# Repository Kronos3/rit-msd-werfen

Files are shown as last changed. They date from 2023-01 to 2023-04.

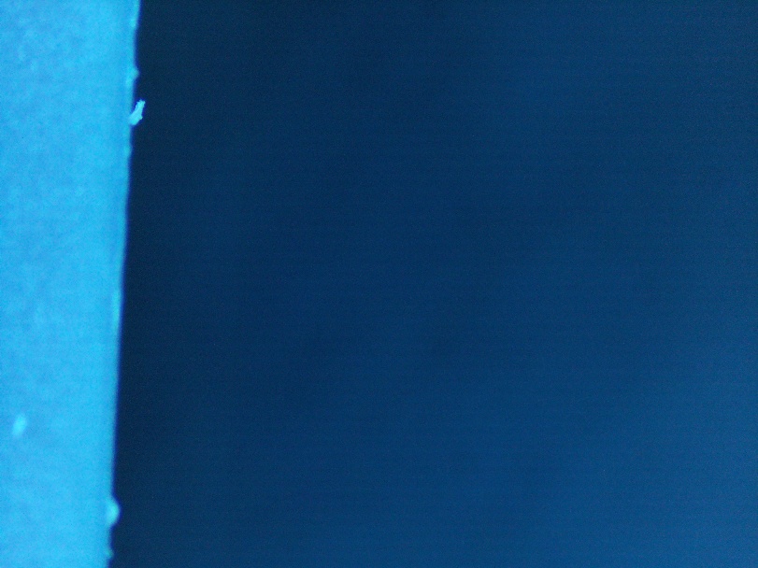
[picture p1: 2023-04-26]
prototyping/test-edge.jpg

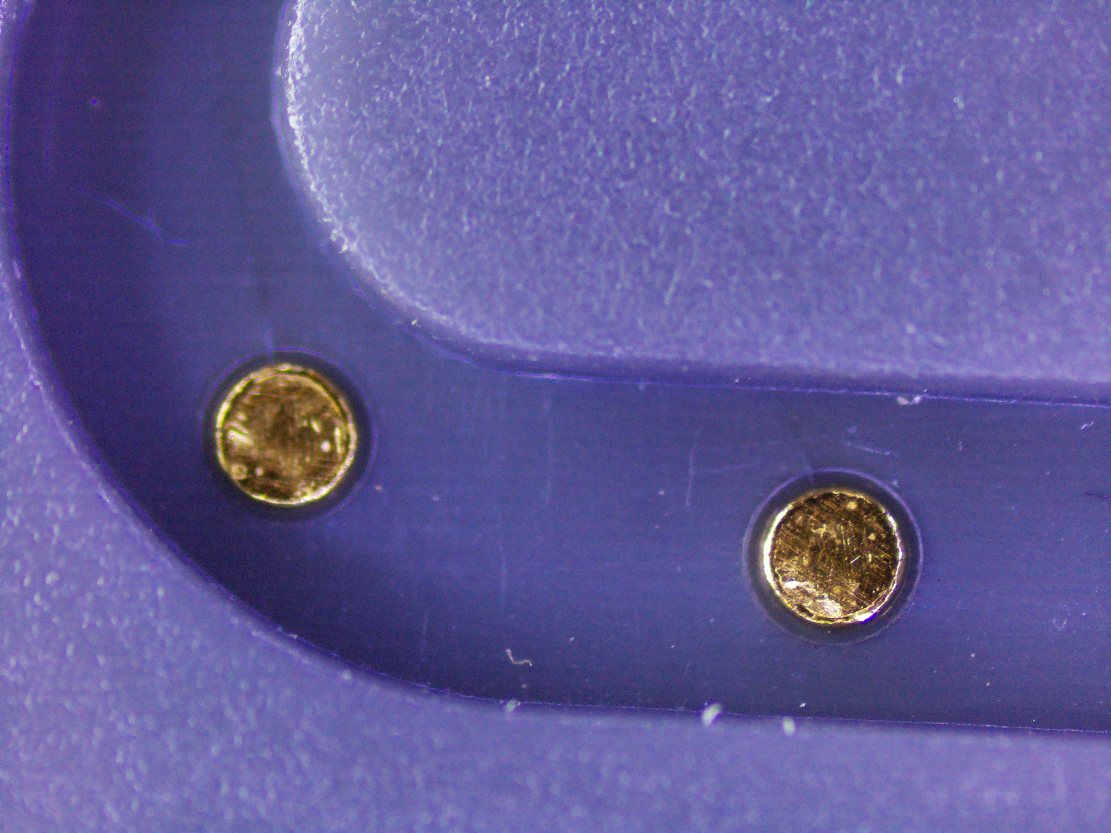
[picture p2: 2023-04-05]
prototyping/testgold2.jpg

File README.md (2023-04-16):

# RIT-Werfen Inspection

## Overview

Layout for this project:
  - /pcb - KiCAD Design file for the PCB
  - /mc - Microcontroller firmware for STM32L476RG
  - /prototyping - Test images and Jupyter Notebooks used to prototype code
  - /src - Code running on the Raspberry Pi and in the browser
    - frontend/ - ReactJS (Typescript) program for frontend browser code
    - rit/ - Middleware that abstract the behavior of cameras and MC packet interface
    - web/ - FastAPI that exposes webendpoints for the frontend to submit requests to
    - camera_focusing.py - Script that boots up a QT Program to view the camera live

## Building

The microcontroller code can be built using CMake + GCC Arm toolchain.
You should use a relatively recent GCC Arm toolchain (`arm-none-eabi-gcc`)

### Dependency installation (Ubuntu)

On Ubuntu, run the following to install the dependencies:

```
sudo apt install gcc-arm-none-eabi cmake make
```

### Building PCB code

```
mkdir -p mc/build
cd mc/build
cmake -DCMAKE_C_COMPILER=arm-none-eabi-gcc -DCMAKE_CXX_COMPILER=arm-none-eabi-g++ ../
```

Now that the code is built, you can flash the PCB using an ST-Link or the ST-Link found on a STM32 Nucleo board using SWD via OpenOCD. I'd recommend using a Nucleo board for flashing along with an IDE like CLion that can set up, build and flash firmware for you.

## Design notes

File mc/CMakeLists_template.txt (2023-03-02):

#THIS FILE IS AUTO GENERATED FROM THE TEMPLATE! DO NOT CHANGE!
set(CMAKE_SYSTEM_NAME Generic)
set(CMAKE_SYSTEM_VERSION 1)
cmake_minimum_required(VERSION 3.20)

# specify cross compilers and tools
set(CMAKE_TRY_COMPILE_TARGET_TYPE STATIC_LIBRARY)

# project settings
project(Werfen C CXX ASM)
set(CMAKE_CXX_STANDARD 14)
set(CMAKE_C_STANDARD 99)

#Uncomment for hardware floating point
add_compile_definitions(ARM_MATH_CM4;ARM_MATH_MATRIX_CHECK;ARM_MATH_ROUNDING)
add_compile_options(-mfloat-abi=hard -mfpu=fpv4-sp-d16)
add_link_options(-mfloat-abi=hard -mfpu=fpv4-sp-d16)

#Uncomment for software floating point
#add_compile_options(-mfloat-abi=soft)

add_compile_options(-mcpu=cortex-m4 -mthumb -mthumb-interwork)
add_compile_options(-ffunction-sections -fdata-sections -fno-common -fmessage-length=0)

# uncomment to mitigate c++17 absolute addresses warnings
#set(CMAKE_CXX_FLAGS "${CMAKE_CXX_FLAGS} -Wno-register")

if ("${CMAKE_BUILD_TYPE}" STREQUAL "Release")
    message(STATUS "Maximum optimization for speed")
    add_compile_options(-Ofast)
elseif ("${CMAKE_BUILD_TYPE}" STREQUAL "RelWithDebInfo")
    message(STATUS "Maximum optimization for speed, debug info included")
    add_compile_options(-Ofast -g)
elseif ("${CMAKE_BUILD_TYPE}" STREQUAL "MinSizeRel")
    message(STATUS "Maximum optimization for size")
    add_compile_options(-Os)
else ()
    message(STATUS "Minimal optimization, debug info included")
    add_compile_options(-Og -g)
endif ()

include_directories(
        Core/Inc
        Drivers/STM32L4xx_HAL_Driver/Inc
        Drivers/STM32L4xx_HAL_Driver/Inc/Legacy
        Drivers/CMSIS/Device/ST/STM32L4xx/Include
        Drivers/CMSIS/Include
        Core/Inc
        Drivers/STM32L4xx_HAL_Driver/Inc
        Drivers/STM32L4xx_HAL_Driver/Inc/Legacy
        Drivers/CMSIS/Device/ST/STM32L4xx/Include
        Drivers/CMSIS/Include
)

add_definitions(
        -DDEBUG
        -DUSE_HAL_DRIVER
        -DSTM32L476xx
        -DDEBUG
        -DUSE_HAL_DRIVER
        -DSTM32L476xx)

file(GLOB_RECURSE SOURCES
        "Core/*.*"
        "Drivers/STM32L4xx_HAL_Driver/*.*"
        )

set(LINKER_SCRIPT ${CMAKE_SOURCE_DIR}/STM32L476RGTX_FLASH.ld)

add_link_options(-Wl,-gc-sections,--print-memory-usage,-Map=${PROJECT_BINARY_DIR}/${PROJECT_NAME}.map)
add_link_options(-mcpu=cortex-m4 -mthumb -mthumb-interwork)
add_link_options(-T ${LINKER_SCRIPT})

include_directories(src)
add_executable(${PROJECT_NAME}.elf
        ${SOURCES}
        ${LINKER_SCRIPT}
        src/gbl.h
        src/log.c
        src/log.h
        src/crc.c
        src/crc.h
        src/motor.c
        src/motor.h
        src/packet.c
        src/packet.h
        src/switch.c
        src/switch.h
        src/led.c
        src/led.h
        src/circular_buffer.c
        src/circular_buffer.h
)

set(HEX_FILE ${PROJECT_BINARY_DIR}/${PROJECT_NAME}.hex)
set(BIN_FILE ${PROJECT_BINARY_DIR}/${PROJECT_NAME}.bin)

add_custom_command(TARGET ${PROJECT_NAME}.elf POST_BUILD
        COMMAND ${CMAKE_OBJCOPY} -Oihex $<TARGET_FILE:${PROJECT_NAME}.elf> ${HEX_FILE}
        COMMAND ${CMAKE_OBJCOPY} -Obinary $<TARGET_FILE:${PROJECT_NAME}.elf> ${BIN_FILE}
        COMMENT "Building ${HEX_FILE}
Building ${BIN_FILE}")

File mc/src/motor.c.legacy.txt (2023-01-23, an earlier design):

//
// Created by tumbar on 1/18/23.
//

#include "motor.h"
#include "log.h"

#include "config.h"
#include "switch.h"

extern TIM_HandleTypeDef htim1;

static I32 motor_position = 0;
static struct
{
    Bool direction_reversed;
    motor_step_t step;
    I32 n;
    motor_state_t state;
    void (*reply_cb)(Status status);
} motor_request = {
        .direction_reversed = FALSE,
        .step = MOTOR_STEP_FULL,
        .n = 0,
        .state = MOTOR_STATE_IDLE,
        .reply_cb = NULL,
};

static void motor_run_request(motor_step_t step, I32 n,
                              MotorReply reply_cb)
{
    motor_request.step = step;
    motor_request.n = n;
    motor_request.state = MOTOR_STATE_SETUP;
    motor_request.direction_reversed = FALSE;
    motor_request.reply_cb = reply_cb;

    if (motor_request.n < 0)
    {
        motor_request.direction_reversed = TRUE;
        motor_request.n = -motor_request.n;
    }

    HAL_TIM_Base_Start_IT(&htim1);
}

static void motor_stop(Status status)
{
    motor_request.step = 0;
    motor_request.n = 0;
    motor_request.state = MOTOR_STATE_IDLE;
    motor_request.direction_reversed = FALSE;

    if (motor_request.reply_cb)
    {
        motor_request.reply_cb(status);
    }

    motor_request.reply_cb = NULL;

    HAL_TIM_Base_Stop_IT(&htim1);
}

static I32 motor_get_step_size(motor_step_t step)
{
    switch(step)
    {
        case MOTOR_STEP_FULL: return 16;
        case MOTOR_STEP_HALF: return 8;
        case MOTOR_STEP_QUARTER: return 4;
        case MOTOR_STEP_EIGHTH: return 2;
        case MOTOR_STEP_SIXTEENTH: return 1;
    }
}

void motor_tick(void)
{
    // Check if E-stop signal
    if (switch_e_stop_set() || motor_request.state == MOTOR_STATE_ESTOP)
    {
        motor_request.state = MOTOR_STATE_ESTOP;
    }
    else if (switch_limit_a_set()
             || switch_limit_b_set())
    {
        motor_request.state = MOTOR_STATE_EXIT;
    }

    switch(motor_request.state)
    {
        case MOTOR_STATE_SETUP:
            // Set up the step size logic levels
            HAL_GPIO_WritePin(MS1_PORT, MS1_PIN, (motor_request.step & MOTOR_PIN_MS1) ? GPIO_PIN_SET : GPIO_PIN_RESET);
            HAL_GPIO_WritePin(MS2_PORT, MS2_PIN, (motor_request.step & MOTOR_PIN_MS2) ? GPIO_PIN_SET : GPIO_PIN_RESET);
            HAL_GPIO_WritePin(MS3_PORT, MS3_PIN, (motor_request.step & MOTOR_PIN_MS3) ? GPIO_PIN_SET : GPIO_PIN_RESET);

            // Enable the controller if needed
            HAL_GPIO_WritePin(ENABLE_PORT, ENABLE_PIN, GPIO_PIN_RESET);

            // Step should already be low
            HAL_GPIO_WritePin(STEP_PORT, STEP_PIN, GPIO_PIN_RESET);

            // Go forwards or backwards
            HAL_GPIO_WritePin(DIR_PORT, DIR_PIN, motor_request.direction_reversed ? GPIO_PIN_SET : GPIO_PIN_RESET);

            motor_request.state = MOTOR_STATE_STEP_RISING;
            break;
        case MOTOR_STATE_STEP_RISING:
            // Check if there are any cycles left
            if (motor_request.n > 0)
            {
                HAL_GPIO_WritePin(STEP_PORT, STEP_PIN, GPIO_PIN_SET);
                motor_request.state = MOTOR_STATE_STEP_HIGH_HOLD;

                // The motor steps on a rising STEP edge
                // Increment the internal motor position
                motor_position += motor_get_step_size(motor_request.step) *
                        (motor_request.direction_reversed ? -1 : 1);
                break;
            }
            // No more cycles, fallthrough
        case MOTOR_STATE_EXIT:
        case MOTOR_STATE_IDLE:
            motor_stop(STATUS_SUCCESS);
            break;
        case MOTOR_STATE_STEP_HIGH_HOLD:
            motor_request.state = MOTOR_STATE_STEP_FALLING;
            break;
        case MOTOR_STATE_STEP_FALLING:
            HAL_GPIO_WritePin(STEP_PORT, STEP_PIN, GPIO_PIN_RESET);
            motor_request.n--;
            motor_request.state = MOTOR_STATE_STEP_LOW_HOLD;
            break;
        case MOTOR_STATE_STEP_LOW_HOLD:
            // Next cycle
            motor_request.state = MOTOR_STATE_STEP_RISING;
            break;
        case MOTOR_STATE_ESTOP:
            // Disable the controller
            HAL_GPIO_WritePin(ENABLE_PORT, ENABLE_PIN, GPIO_PIN_SET);

            // Once the ESTOP is tripped during an executing motor request,
            //   we will hang here forever. The only way to exit out of this
            //   state is to release the ESTOP and hard reset the microcontroller
            motor_stop(STATUS_FAILURE);
            break;
    }
}

static Status motor_is_ready(motor_step_t step)
{
    switch(step)
    {
        case MOTOR_STEP_FULL:
        case MOTOR_STEP_HALF:
        case MOTOR_STEP_QUARTER:
        case MOTOR_STEP_EIGHTH:
        case MOTOR_STEP_SIXTEENTH:
            log_printf("Invalid step size %d", step);
            return STATUS_FAILURE;
    }

    if (motor_request.state != MOTOR_STATE_IDLE)
    {
        log_printf("Motor is busy with another request, state %d", motor_request.state);
        return STATUS_FAILURE;
    }

    return STATUS_SUCCESS;
}

Status motor_step(motor_step_t step, I32 n, MotorReply reply_cb)
{
    if (motor_is_ready(step) != STATUS_SUCCESS)
    {
        return STATUS_FAILURE;
    }

    motor_run_request(step, n, reply_cb);
    return STATUS_SUCCESS;
}

I32 motor_get_position(void)
{
    return motor_position;
}

void motor_set_position(I32 position)
{
    motor_position = position;
}

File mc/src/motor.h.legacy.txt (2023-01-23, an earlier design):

//
// Created by tumbar on 1/18/23.
//

#ifndef MC_MOTOR_H
#define MC_MOTOR_H

#include "gbl.h"

typedef enum
{
    MOTOR_STEP_FULL = 0,
    MOTOR_STEP_HALF = 1,
    MOTOR_STEP_QUARTER = 2,
    MOTOR_STEP_EIGHTH = 3,
    MOTOR_STEP_SIXTEENTH = 7,
} motor_step_t;

typedef enum
{
    MOTOR_PIN_MS1 = 1 << 0,
    MOTOR_PIN_MS2 = 1 << 1,
    MOTOR_PIN_MS3 = 1 << 2,
} motor_pin_mask;

typedef enum
{
    /**
     * The idle state will stop the running motor request
     * Nominally this should not run in the motor tick
     */
    MOTOR_STATE_IDLE,

    /**
     * Set the MS1 MS2 & MS3 control
     * lines to the correct state to select
     * the step size
     */
    MOTOR_STATE_SETUP,

    /**
     * Rising edge on the step signal will run
     * a single step with the selected MS lines
     * from the setup step.
     */
    MOTOR_STATE_STEP_RISING,

    /**
     * Holds the signal high so that it stays high
     * for two clock cycles
     */
    MOTOR_STATE_STEP_HIGH_HOLD,

    /**
     * Drop the step down to low to prepare for the next
     * step
     */
    MOTOR_STATE_STEP_FALLING,

    /**
     * Keep the signal low for a second clock cycle
     */
    MOTOR_STATE_STEP_LOW_HOLD,

    /**
     * E-stop has been hit, keep the timer running to keep checking
     * the E-stop condition. This MC doesn't have an EXTI meaning
     * we need to poll via the timer
     */
    MOTOR_STATE_ESTOP,

    /**
     * This state is an early exit state that will clean up the
     * step controller signaling.
     */
    MOTOR_STATE_EXIT,
} motor_state_t;

typedef void (*MotorReply)(Status status);

/**
 * Apply n steps to the motor
 * @param step Step size
 * @param n number of steps
 * @param reply_cb callback when motor request is done
 */
Status motor_step(motor_step_t step, I32 n, MotorReply reply_cb);

/**
 * Get the position of the motor on the stage
 * @return position in SIXTEENTH steps
 */
I32 motor_get_position(void);

/**
 * Get the current motor state
 * @return motor state
 */
motor_state_t motor_state(void);

/**
 * Set the motor position. This does not move the
 * motor. It just sets the motor position internally
 * Useful if a limit switch is hit
 * @param position Position to set the motor to
 */
void motor_set_position(I32 position);

/**
 * Run a single 0.5us clock cycle for our driver
 * Used only during an executing motor request
 */
void motor_tick(void);

#endif //MC_MOTOR_H

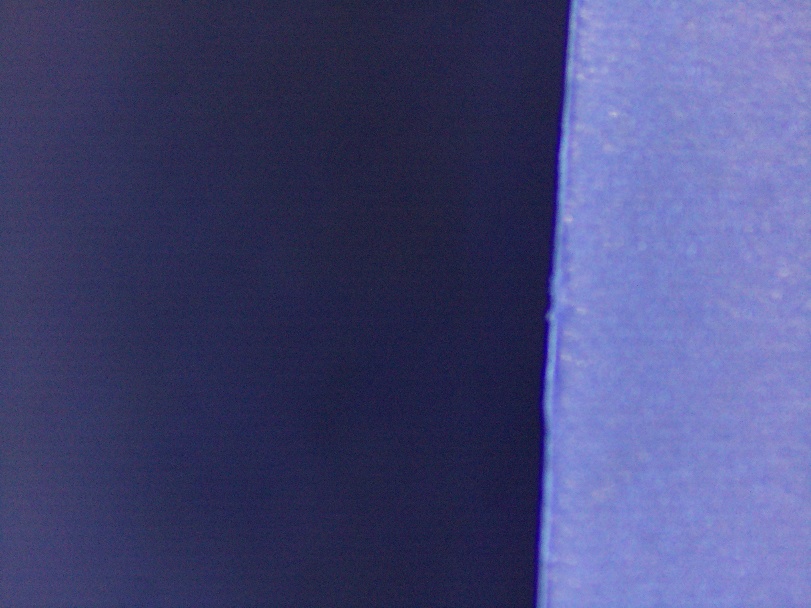
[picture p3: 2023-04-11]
prototyping/edge-misaligned.jpeg

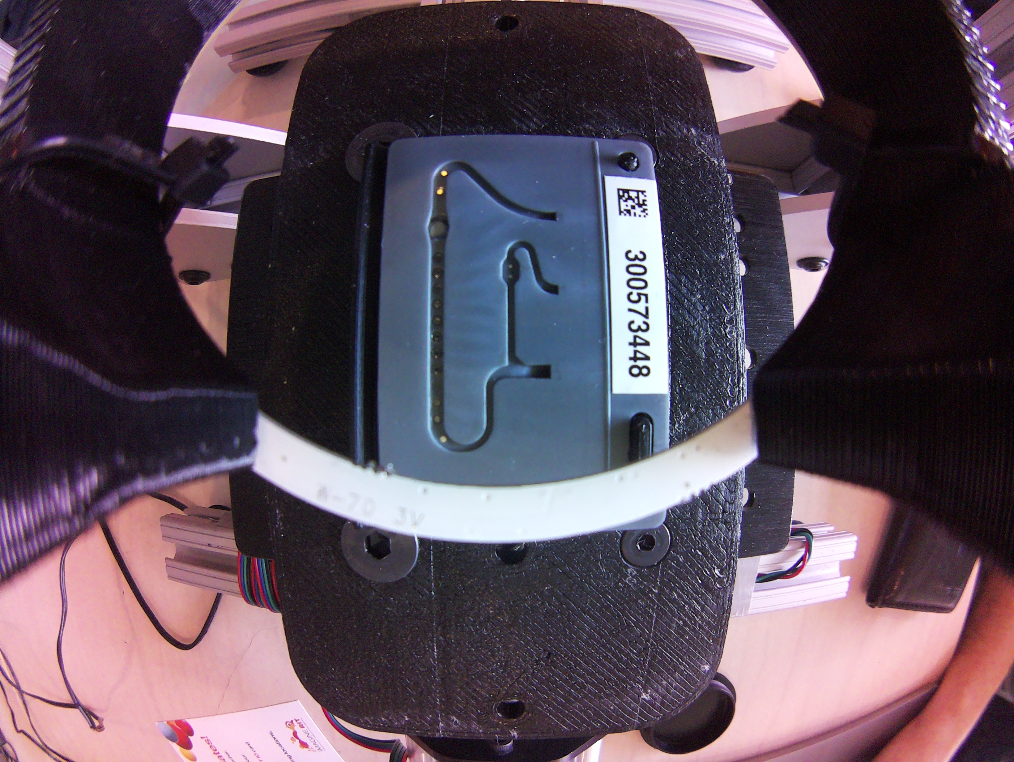
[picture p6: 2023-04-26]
prototyping/aux_cam.jpg

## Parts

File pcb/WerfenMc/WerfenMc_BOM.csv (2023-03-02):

Designator | Qnty | Comment | Name | Footprint | Description | JLCPCB Part #
C1, | 1 | 1uF | C | Capacitor_Tantalum_SMD:CP_EIA-2012-12_Kemet-R | Unpolarized capacitor | C28323
C2, | 1 | 10nF | C | Capacitor_Tantalum_SMD:CP_EIA-2012-12_Kemet-R | Unpolarized capacitor | C1710
C3, | 1 | 4.7uF | C | Capacitor_Tantalum_SMD:CP_EIA-2012-12_Kemet-R | Unpolarized capacitor | C17779
C4, C5, C6, C7, C8, C16, | 6 | 100nF | C | Capacitor_SMD:C_0402_1005Metric | Unpolarized capacitor | C1525
C9, C10, | 2 | 20pF | C | Capacitor_SMD:C_0402_1005Metric | Unpolarized capacitor | C1554
C14, | 1 | 100uF | C_Polarized | Capacitor_SMD:C_Elec_8x5.4 | Polarized capacitor | C72481
C15, | 1 | 1000uF | C_Polarized | Capacitor_SMD:C_Elec_8x5.4 | Polarized capacitor | C99833
D1, D2, D3, D4, D5, D6, D7, D10 | 8 | LED Red | LED | LED_SMD:LED_0805_2012Metric | Light emitting diode | C84256
D8, | 1 | D_Schottky | D_Schottky | Diode_SMD:D_0805_2012Metric | Schottky diode | C35722
FB1, | 1 | FerriteBead | FerriteBead | Inductor_SMD:L_0603_1608Metric | Ferrite bead | C1002
HSE1, | 1 | 8MHz | Crystal | Crystal:Crystal_SMD_TXC_7A-2Pin_5x3.2mm | Two pin crystal | C115962
Q2, | 1 | BCP56 | BCP56 | Package_TO_SOT_SMD:SOT-223 | 1A Ic, 80V Vce, NPN Medium Power Transistor, SOT-223 | C95810
R2, R9, R10, R13, R15, | 5 | 10k | R | Resistor_SMD:R_0402_1005Metric | Resistor | C25744
R3, R4, R5, R6, R11, R12, R14, R17, | 8 | 160 | R | Resistor_SMD:R_0402_1005Metric | Resistor | C25087
R7, | 1 | 390 | R | Resistor_SMD:R_0402_1005Metric | Resistor | C25102
R8, | 1 | 1k | R | Resistor_SMD:R_0402_1005Metric | Resistor | C11702
R16, | 1 | 100 | R | Resistor_SMD:R_0603_1608Metric | Resistor | C22775
U1, | 1 | STM32L476RGTx | STM32L476RGTx | Package_QFP:LQFP-64_10x10mm_P0.5mm | ARM Cortex-M4 MCU, 1024KB flash, 128KB RAM, 80MHz, 1.71-3.6V, 51 GPIO, LQFP-64 | C74797
U2, | 1 | LM2576HVS-5 | LM2576HVS-5 | Package_TO_SOT_SMD:TO-263-5_TabPin3 | 5V 3A, SIMPLE SWITCHER® Step-Down Voltage Regulator, High Voltage Input, TO-263 | C234209
U3, | 1 | AMS1117CD-3.3 | AMS1117CD-3.3 | Package_TO_SOT_SMD:TO-252-3_TabPin2 | 1A Low Dropout regulator, positive, 3.3V fixed output, TO-252 | C841796

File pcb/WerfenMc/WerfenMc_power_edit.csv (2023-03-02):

Source: | /home/tumbar/git/msd-gem-5000/pcb/WerfenMc/WerfenMc_power_edit.kicad_sch
Date: | Thu 16 Feb 2023 08:46:09 AM EST
Tool: | Eeschema 6.0.10-86aedd382b~118~ubuntu22.10.1
Generator: | /usr/share/kicad/plugins/bom_csv_grouped_by_value_with_fp.py
Component Count: | 67
Ref | Qnty | Value | Cmp name | Footprint | Description | Vendor
C1, | 1 | 1u | C | Capacitor_Tantalum_SMD:CP_EIA-2012-12_Kemet-R | Unpolarized capacitor
C2, | 1 | 10n | C | Capacitor_Tantalum_SMD:CP_EIA-2012-12_Kemet-R | Unpolarized capacitor
C3, | 1 | 4.7u | C | Capacitor_Tantalum_SMD:CP_EIA-2012-12_Kemet-R | Unpolarized capacitor
C4, C5, C6, C7, C8, C16, | 6 | 100n | C | Capacitor_SMD:C_0402_1005Metric | Unpolarized capacitor
C9, C10, | 2 | 20p | C | Capacitor_SMD:C_0402_1005Metric | Unpolarized capacitor
C14, | 1 | 100u | C_Polarized | Capacitor_SMD:C_Elec_8x5.4 | Polarized capacitor
C15, | 1 | 1000u | C_Polarized | Capacitor_SMD:C_Elec_8x5.4 | Polarized capacitor
D1, | 1 | MS1 | LED | LED_SMD:LED_0805_2012Metric | Light emitting diode
D2, | 1 | MS2 | LED | LED_SMD:LED_0805_2012Metric | Light emitting diode
D3, | 1 | MS3 | LED | LED_SMD:LED_0805_2012Metric | Light emitting diode
D4, | 1 | USR | LED | LED_SMD:LED_0805_2012Metric | Light emitting diode
D5, | 1 | E | LED | LED_SMD:LED_0805_2012Metric | Light emitting diode
D6, | 1 | S1 | LED | LED_SMD:LED_0805_2012Metric | Light emitting diode
D7, | 1 | S2 | LED | LED_SMD:LED_0805_2012Metric | Light emitting diode
D8, | 1 | D_Schottky | D_Schottky | cad:SS36-E3&slash_57T | Schottky diode
D9, | 1 | LIGHT | LEDRemapped | TerminalBlock_Phoenix:TerminalBlock_Phoenix_MPT-0,5-2-2.54_1x02_P2.54mm_Horizontal | Light emitting diode
D10, | 1 | PWR | LED | LED_SMD:LED_0805_2012Metric | Light emitting diode
FB1, | 1 | FerriteBead | FerriteBead | Inductor_SMD:L_0603_1608Metric | Ferrite bead
H1, H2, H3, H4, | 4 | MountingHole | MountingHole | MountingHole:MountingHole_2.2mm_M2 | Mounting Hole without connection
HSE1, | 1 | 8M | Crystal | Crystal:Crystal_SMD_TXC_7A-2Pin_5x3.2mm | Two pin crystal
J1, | 1 | MOTOR | Conn_01x04_Male | Connector_PinHeader_2.54mm:PinHeader_1x04_P2.54mm_Vertical | Generic connector, single row, 01x04, script generated (kicad-library-utils/schlib/autogen/connector/)
J2, | 1 | SWD | Conn_01x05_Male | Connector_PinHeader_2.54mm:PinHeader_1x05_P2.54mm_Vertical | Generic connector, single row, 01x05, script generated (kicad-library-utils/schlib/autogen/connector/)
J3, | 1 | POWER | Barrel_Jack_Switch | Connector_BarrelJack:BarrelJack_Horizontal | DC Barrel Jack with an internal switch
J4, | 1 | UART3 | Conn_01x04_Male | Connector_PinHeader_2.54mm:PinHeader_1x04_P2.54mm_Vertical | Generic connector, single row, 01x04, script generated (kicad-library-utils/schlib/autogen/connector/)
J5, | 1 | UART1 | Conn_01x04_Male | Connector_PinHeader_2.54mm:PinHeader_1x04_P2.54mm_Vertical | Generic connector, single row, 01x04, script generated (kicad-library-utils/schlib/autogen/connector/)
J6, | 1 | PowerTerminal | Conn_01x02_Male | TerminalBlock_Phoenix:TerminalBlock_Phoenix_MPT-0,5-2-2.54_1x02_P2.54mm_Horizontal | Generic connector, single row, 01x02, script generated (kicad-library-utils/schlib/autogen/connector/)
JP1, | 1 | BYPASS | SolderJumper_2_Open | Jumper:SolderJumper-2_P1.3mm_Open_Pad1.0x1.5mm | Solder Jumper, 2-pole, open
L1, | 1 | 68u | L | cad:SRP1040VA-1R5M | Inductor
Q1, | 1 | Q_Photo_NPN | Q_Photo_NPN | Connector_PinHeader_2.54mm:PinHeader_1x02_P2.54mm_Vertical | NPN phototransistor, collector/emitter
Q2, | 1 | BCP56 | BCP56 | Package_TO_SOT_SMD:SOT-223 | 1A Ic, 80V Vce, NPN Medium Power Transistor, SOT-223
R1, | 1 | 2k | R | Resistor_THT:R_Axial_DIN0411_L9.9mm_D3.6mm_P15.24mm_Horizontal | Resistor
R2, R9, R10, R13, R15, | 5 | 10k | R | Resistor_SMD:R_0402_1005Metric | Resistor
R3, R4, R5, R6, R11, R12, R14, R17, | 8 | 160 | R | Resistor_SMD:R_0402_1005Metric | Resistor
R7, | 1 | 390 | R | Resistor_SMD:R_0402_1005Metric | Resistor
R8, | 1 | 1k | R | Resistor_SMD:R_0402_1005Metric | Resistor
R16, | 1 | 100 | R | Resistor_SMD:R_0603_1608Metric | Resistor
S1, | 1 | BOOT | EG1218 | digikey-footprints:Switch_Slide_11.6x4mm_EG1218 | SWITCH SLIDE SPDT 200MA 30V
SW1, | 1 | RESET | SW_Push | Button_Switch_THT:SW_PUSH_6mm | Push button switch, generic, two pins
TP1, | 1 | STEP_TP | TestPoint | TestPoint:TestPoint_Pad_D1.5mm | test point
TP2, | 1 | 3V3_TP | TestPoint | TestPoint:TestPoint_Pad_D1.5mm | test point
TP3, | 1 | 12V_TP | TestPoint | TestPoint:TestPoint_Pad_D1.5mm | test point
TP5, | 1 | S1_TP | TestPoint | TestPoint:TestPoint_Pad_D1.5mm | test point
TP6, | 1 | S2_TP | TestPoint | TestPoint:TestPoint_Pad_D1.5mm | test point
TP8, | 1 | 5V_TP | TestPoint | TestPoint:TestPoint_Pad_D1.5mm | test point
U1, | 1 | STM32L476RGTx | STM32L476RGTx | Package_QFP:LQFP-64_10x10mm_P0.5mm | ARM Cortex-M4 MCU, 1024KB flash, 128KB RAM, 80MHz, 1.71-3.6V, 51 GPIO, LQFP-64
U2, | 1 | LM2576HVS-5 | LM2576HVS-5 | Package_TO_SOT_SMD:TO-263-5_TabPin3 | 5V 3A, SIMPLE SWITCHER® Step-Down Voltage Regulator, High Voltage Input, TO-263
U3, | 1 | AMS1117CD-3.3 | AMS1117CD-3.3 | Package_TO_SOT_SMD:TO-252-3_TabPin2 | 1A Low Dropout regulator, positive, 3.3V fixed output, TO-252

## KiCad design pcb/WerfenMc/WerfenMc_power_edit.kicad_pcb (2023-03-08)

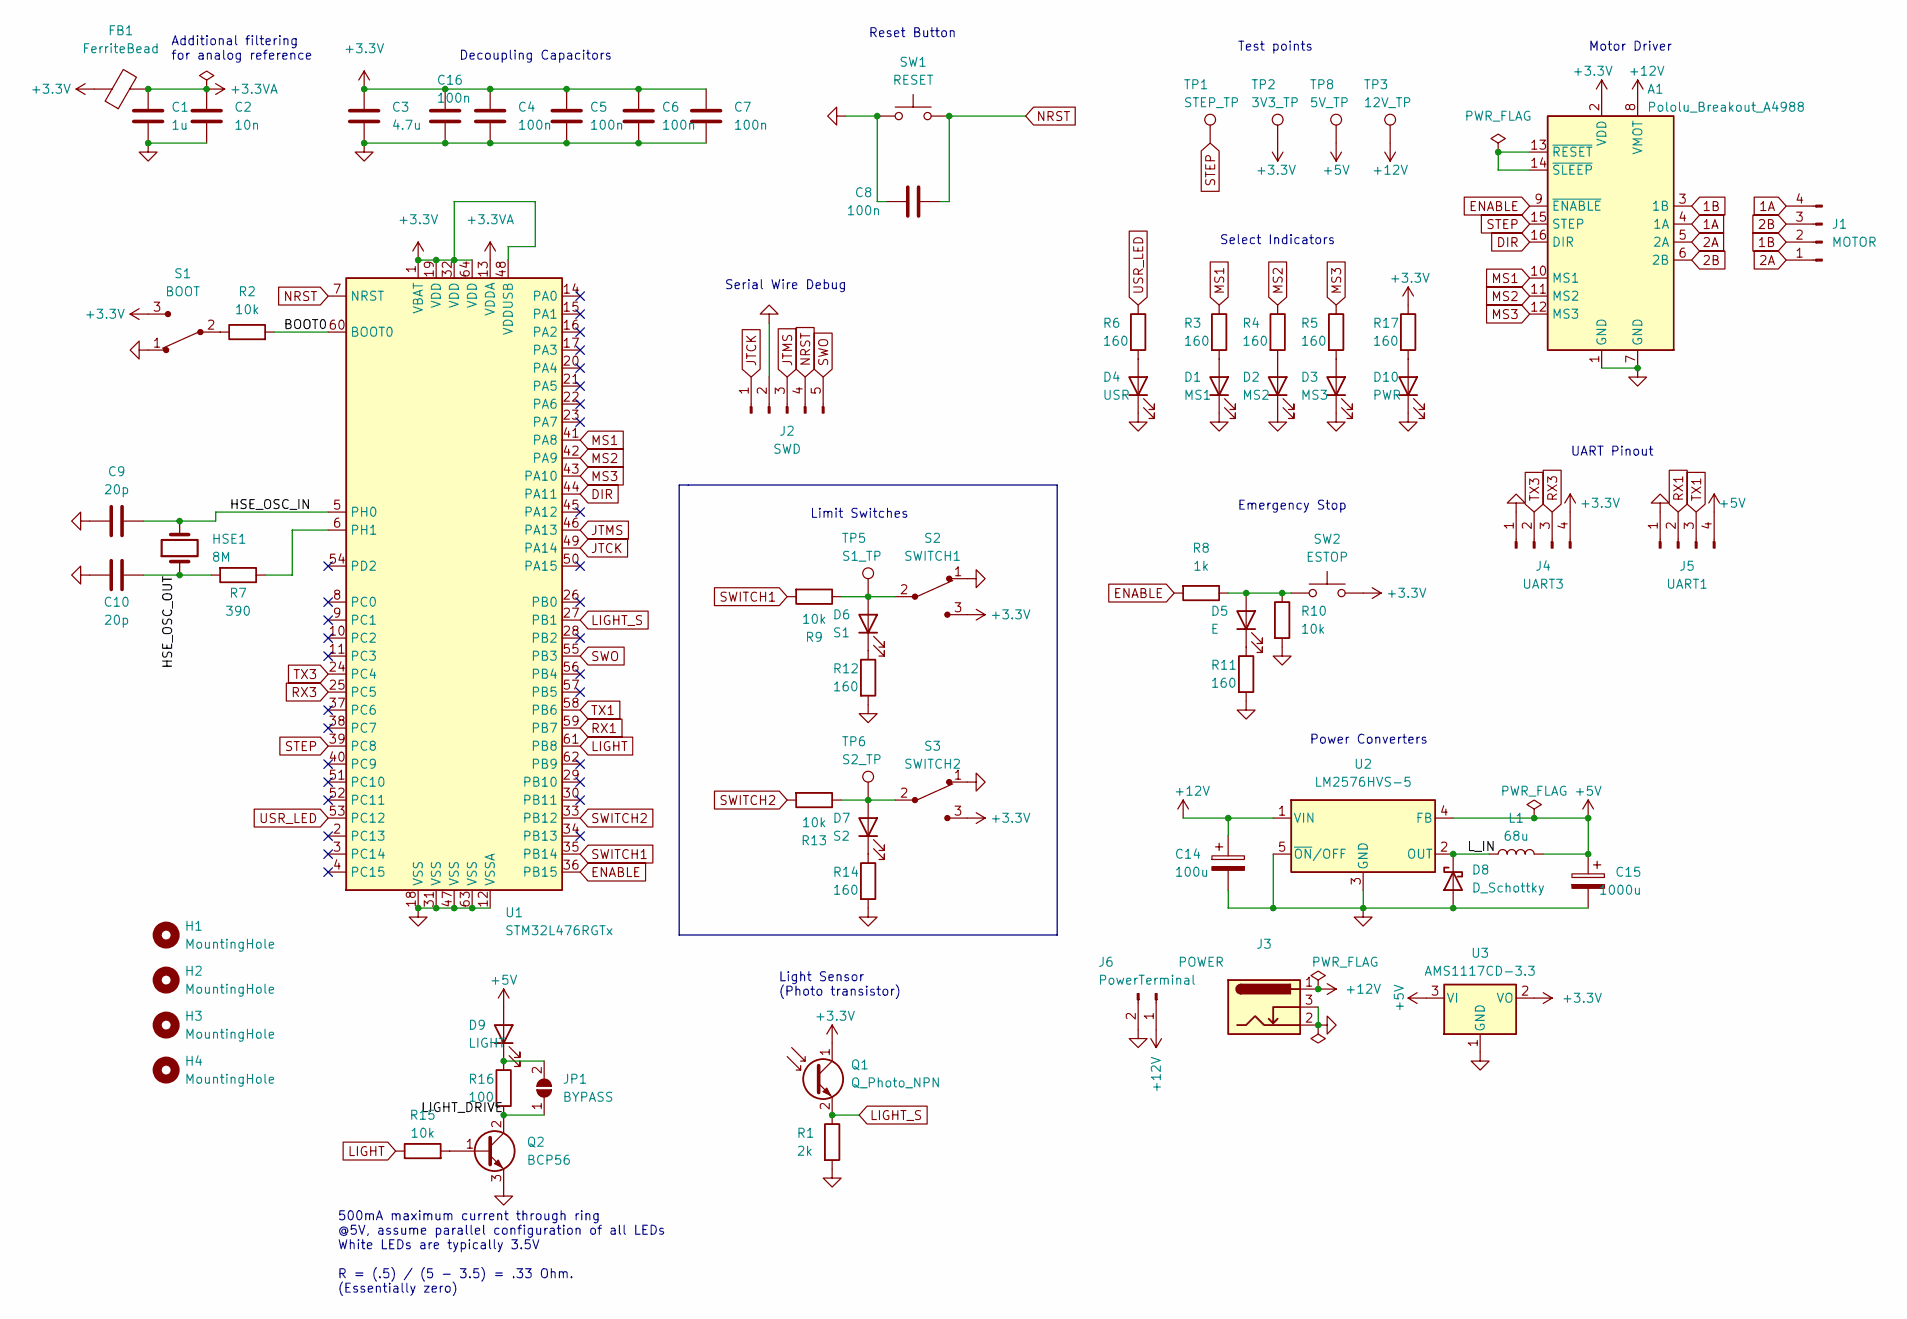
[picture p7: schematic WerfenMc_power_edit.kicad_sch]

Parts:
A1: Pololu_Breakout_A4988; Pololu_Breakout-16_15.2x20.3mm
C1: 1u; CP_EIA-2012-12_Kemet-R
C2: 10n; CP_EIA-2012-12_Kemet-R
C3: 4.7u; CP_EIA-2012-12_Kemet-R
C4, C5, C6, C7, C8, C16: 100n; C_0402_1005Metric
C9, C10: 20p; C_0402_1005Metric
C14: 100u; C_Elec_8x5.4
C15: 1000u; C_Elec_8x5.4
D1: MS1; LED_0805_2012Metric
D2: MS2; LED_0805_2012Metric
D3: MS3; LED_0805_2012Metric
D4: USR; LED_0805_2012Metric
D5: E; LED_0805_2012Metric
D6: S1; LED_0805_2012Metric
D7: S2; LED_0805_2012Metric
D8: D_Schottky; D_SMC
D9: LIGHT; TerminalBlock_Phoenix_MPT-0,5-2-2.54_1x02_P2.54mm_Horizontal
D10: PWR; LED_0805_2012Metric
FB1: FerriteBead; L_0603_1608Metric
H1, H2, H3, H4: MountingHole; MountingHole_2.2mm_M2
HSE1: 8M; Crystal_SMD_MicroCrystal_CC4V-T1A-2Pin_5.0x1.9mm
J1: MOTOR; PinHeader_1x04_P2.54mm_Vertical
J2: SWD; PinHeader_1x05_P2.54mm_Vertical
J3: POWER; BarrelJack_Horizontal
J4: UART3; PinHeader_1x04_P2.54mm_Vertical
J5: UART1; PinHeader_1x04_P2.54mm_Vertical
J6: PowerTerminal; TerminalBlock_Phoenix_MPT-0,5-2-2.54_1x02_P2.54mm_Horizontal
JP1: BYPASS; SolderJumper-2_P1.3mm_Open_Pad1.0x1.5mm
L1: 68u; SRP1040VA-1R5M
Q1: Q_Photo_NPN; PinHeader_1x02_P2.54mm_Vertical
Q2: BCP56; SOT-223
R1: 2k; R_Axial_DIN0411_L9.9mm_D3.6mm_P15.24mm_Horizontal
R2, R9, R10, R13, R15: 10k; R_0402_1005Metric
R3, R4, R5, R6, R11, R12, R14, R17: 160; R_0402_1005Metric
R7: 390; R_0402_1005Metric
R8: 1k; R_0402_1005Metric
R16: 100; R_0603_1608Metric
S1: BOOT; Switch_Slide_11.6x4mm_EG1218; MPN EG1218; Digi-Key_PN EG1903-ND
S2: SWITCH1; PinHeader_1x03_P2.54mm_Vertical; MPN EG1218; Digi-Key_PN EG1903-ND
S3: SWITCH2; PinHeader_1x03_P2.54mm_Vertical; MPN EG1218; Digi-Key_PN EG1903-ND
SW1: RESET; SW_PUSH_6mm
SW2: ESTOP; PinHeader_1x02_P2.54mm_Vertical
TP1: STEP_TP; TestPoint_Pad_D1.5mm
TP2: 3V3_TP; TestPoint_Pad_D1.5mm
TP3: 12V_TP; TestPoint_Pad_D1.5mm
TP5: S1_TP; TestPoint_Pad_D1.5mm
TP6: S2_TP; TestPoint_Pad_D1.5mm
TP8: 5V_TP; TestPoint_Pad_D1.5mm
U1: STM32L476RGTx; LQFP-64_10x10mm_P0.5mm
U2: LM2576HVS-5; TO-263-5_TabPin3
U3: AMS1117CD-3.3; TO-252-3_TabPin2

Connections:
1A: A1.4 (1A), J1.4
1B: A1.3 (1B), J1.2
2A: A1.5 (2A), J1.1
2B: A1.6 (2B), J1.3
+3.3V: A1.2 (VDD), C3.1, C4.1, C5.1, C6.1, C7.1, C16.1, FB1.1, J4.4, Q1.1 (C), R17.1, S1.3, S2.3, S3.3, SW2.2, TP2.1, U1.1 (VBAT), U1.19 (VDD), U1.32 (VDD), U1.48 (VDDUSB), U1.64 (VDD), U3.2 (VO)
+3.3VA: C1.1, C2.1, FB1.2, U1.13 (VDDA)
+5V: C15.1, D9.1 (A), J5.4, L1.2, TP8.1, U2.4 (FB), U3.3 (VI)
+12V: A1.8 (VMOT), C14.1, J3.1, J6.1, TP3.1, U2.1 (VIN)
/BOOT0: R2.2, U1.60 (BOOT0)
/HSE_OSC_IN: C9.2, HSE1.2, U1.5 (PH0)
/HSE_OSC_OUT: C10.2, HSE1.1, R7.2
/LIGHT_DRIVE: JP1.1 (A), Q2.2 (C), Q2.4 (C), R16.2
/L_IN: D8.1 (K), L1.1, U2.2 (OUT)
DIR: A1.16 (DIR), U1.44 (PA11)
ENABLE: A1.9 (~ENABLE), R8.2, U1.36 (PB15)
GND: A1.1 (GND), A1.7 (GND), C1.2, C2.2, C3.2, C4.2, C5.2, C6.2, C7.2, C8.2, C9.1, C10.1, C14.2, C15.2, C16.2, D1.1 (K), D2.1 (K), D3.1 (K), D4.1 (K), D8.2 (A), D10.1 (K), J2.2, J3.2, J3.3, J4.1, J5.1, J6.2, Q2.3 (E), R1.2, R10.2, R11.2, R12.2, R14.2, S1.1, S2.1, S3.1, SW1.1, U1.12 (VSSA), U1.18 (VSS), U1.31 (VSS), U1.47 (VSS), U1.63 (VSS), U2.3 (GND), U2.5 (~ON/OFF), U3.1 (GND)
JTCK: J2.1, U1.49 (PA14)
JTMS: J2.3, U1.46 (PA13)
LIGHT: R15.1, U1.61 (PB8)
LIGHT_S: Q1.2 (E), R1.1, U1.27 (PB1)
MS1: A1.10 (MS1), R3.1, U1.41 (PA8)
MS2: A1.11 (MS2), R4.1, U1.42 (PA9)
MS3: A1.12 (MS3), R5.1, U1.43 (PA10)
NRST: C8.1, J2.4, SW1.2, U1.7 (NRST)
unnamed: A1.13 (~RESET), A1.14 (~SLEEP)
unnamed: D1.2 (A), R3.2
unnamed: D2.2 (A), R4.2
unnamed: D3.2 (A), R5.2
unnamed: D4.2 (A), R6.2
unnamed: D5.1 (K), R11.1
unnamed: D5.2 (A), R8.1, R10.1, SW2.1
unnamed: D6.1 (K), R12.1
unnamed: D6.2 (A), R9.1, S2.2, TP5.1
unnamed: D7.1 (K), R14.1
unnamed: D7.2 (A), R13.1, S3.2, TP6.1
unnamed: D9.2 (K), JP1.2 (B), R16.1
unnamed: D10.2 (A), R17.2
unnamed: Q2.1 (B), R15.2
unnamed: R2.1, S1.2
unnamed: R7.1, U1.6 (PH1)
RX1: J5.2, U1.59 (PB7)
RX3: J4.3, U1.25 (PC5)
STEP: A1.15 (STEP), TP1.1, U1.39 (PC8)
SWITCH1: R9.2, U1.35 (PB14)
SWITCH2: R13.2, U1.33 (PB12)
SWO: J2.5, U1.55 (PB3)
TX1: J5.3, U1.58 (PB6)
TX3: J4.2, U1.24 (PC4)
USR_LED: R6.1, U1.53 (PC12)

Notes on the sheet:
UART Pinout
Serial Wire Debug
Additional filtering for analog reference
Test points
Decoupling Capacitors
Power Converters
500mA maximum current through ring @5V, assume parallel configuration of all LEDs White LEDs are typically 3.5V R = (.5) / (5 - 3.5) = .33 Ohm. (Essentially zero)
Select Indicators
Reset Button
Emergency Stop
Light Sensor (Photo transistor)
Motor Driver
Limit Switches

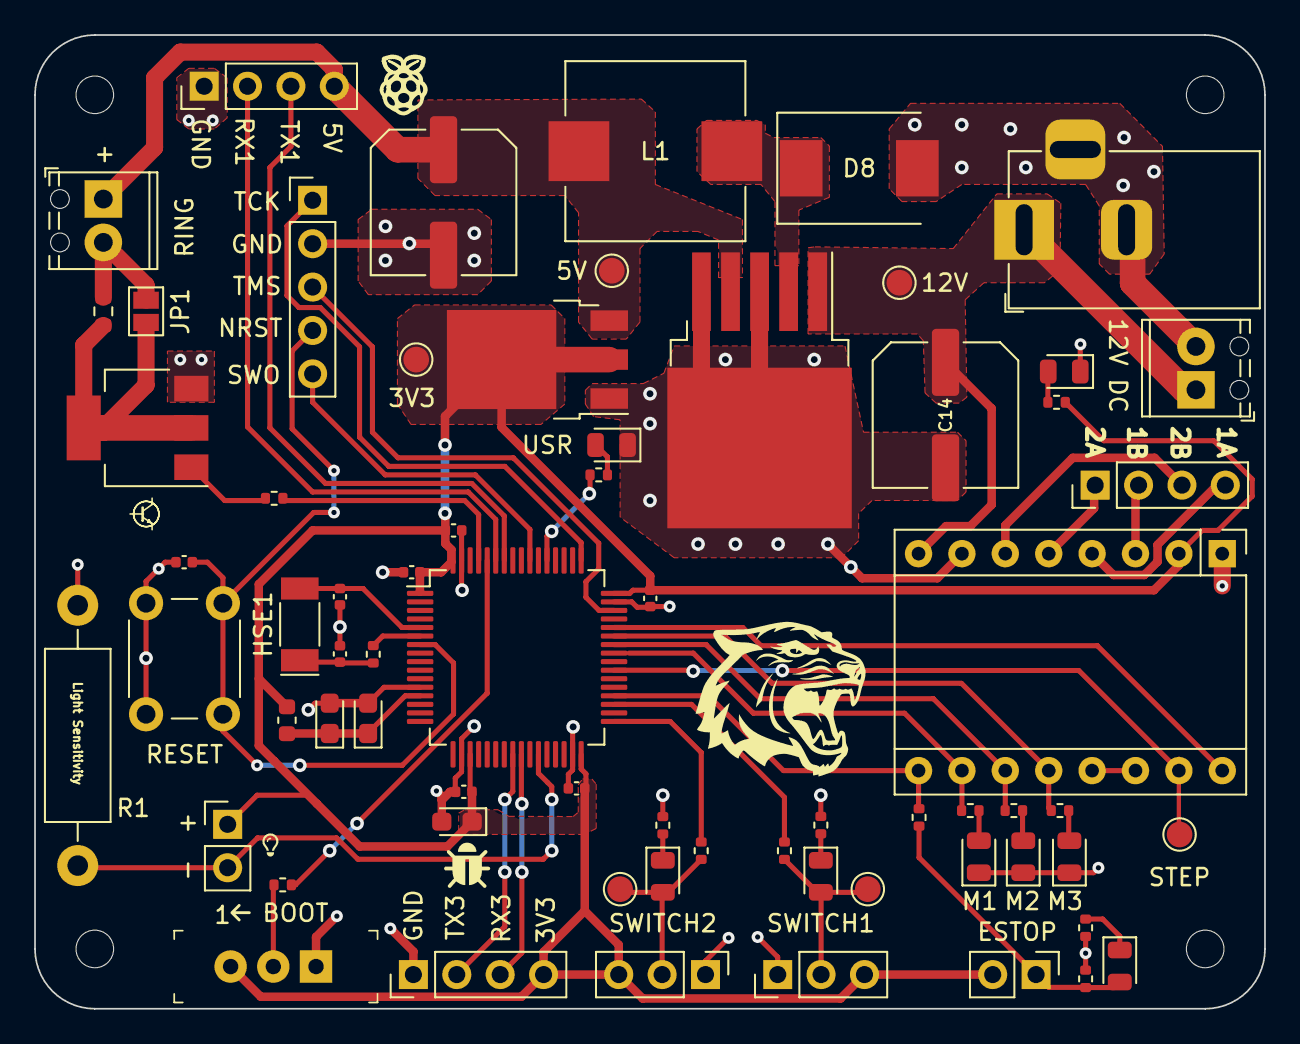
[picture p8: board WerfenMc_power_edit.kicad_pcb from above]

Board: 2 copper layers, 72.0 x 57.0 mm, 71 parts (0 on the bottom side), 49 nets.

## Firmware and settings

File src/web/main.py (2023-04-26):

import asyncio
import datetime
import logging
import os
import shutil
import tempfile
import threading
import time
import typing
from pathlib import Path
from queue import Queue
from typing import Literal, Dict, Tuple, Optional

import cv2
import numpy as np
import serial

from fastapi import FastAPI, Query, HTTPException
from fastapi.responses import Response, PlainTextResponse

from fastapi.middleware.cors import CORSMiddleware
from starlette.background import BackgroundTask
from starlette.requests import Request
from starlette.responses import FileResponse
from starlette.staticfiles import StaticFiles

from rit import processing
from rit.cam import HqCamera, AuxCamera, Camera
from rit.stage import StageStepSize, Stage
from rit.storage import Card, Storage
from rit.system import System

from pydantic import BaseModel

log = logging.getLogger(__name__)

app = FastAPI()

app.add_middleware(
    CORSMiddleware,
    allow_origins=["*"],
    allow_credentials=True,
    allow_methods=["*"],
    allow_headers=["*"],
)

is_dummy = os.getenv("WERFEN_DUMMY")
serial_file = os.getenv("WERFEN_SERIAL")
if is_dummy:
    system = System(Stage(None), HqCamera(-1), AuxCamera(-1))
else:
    if serial_file:
        ser = serial.Serial(serial_file, 115200, timeout=1.0)
    else:
        ser = serial.Serial("/dev/ttyAMA0", 115200, timeout=1.0)
    system = System(Stage(ser), HqCamera(1), AuxCamera(0))

Encodings = Literal["jpeg", "png", "tiff"]
Cameras = Literal["hq", "aux"]


@app.exception_handler(Exception)
def default_exception_handler(request: Request, exc: Exception):
    return PlainTextResponse(str(exc), status_code=500)


class ImageResponse(Response):
    def __init__(self,
                 content: typing.Any = None,
                 scale: float = 0.2,
                 status_code: int = 200,
                 headers: typing.Optional[typing.Mapping[str, str]] = None,
                 media_type: typing.Optional[str] = "image/jpeg",
                 background: typing.Optional[BackgroundTask] = None
                 ):
        self.scale = scale
        super().__init__(content, status_code, headers, media_type, background)

    def render(self, content) -> bytes:
        content = cv2.resize(content, (int(content.shape[1] * self.scale), int(content.shape[0] * self.scale)))

        if self.media_type == "image/jpeg":
            img = cv2.imencode(".jpg", content)[1]
        elif self.media_type == "image/png":
            img = cv2.imencode(".png", content)[1]
        elif self.media_type == "image/tiff":
            img = cv2.imencode(".tiff", content)[1]
        else:
            img = content

        return bytes(img)


class FutureManager:
    _current_id: int
    _futures: Dict[int, asyncio.Future]

    def __init__(self):
        self._futures = {}
        self._current_id = 0

    def create(self) -> Tuple[int, asyncio.Future]:
        fid = self._current_id
        self._current_id += 1

        out = asyncio.Future()
        self._futures[fid] = out

        return fid, out

    def get(self, fid: int) -> asyncio.Future:
        return self._futures[fid]

    def delete(self, fid: int):
        del self._futures[fid]


class SequencedFutureManager:
    _current_id: int
    _futures: Dict[int, Queue]

    def __init__(self):
        self._futures = {}
        self._current_id = 0

    def create(self) -> int:
        fid = self._current_id
        self._current_id += 1

        self._futures[fid] = Queue()
        return fid

    def put(self, fid: int, response):
        self._futures[fid].put(response)

    def get(self, fid: int):
        return self._futures[fid].get()

    def finish(self, fid: int):
        self._futures[fid].put(None)
        del self._futures[fid]


future_manager = FutureManager()
sequenced_future_manager = SequencedFutureManager()

app.mount("/assets", StaticFiles(directory="frontend/dist/assets"), name="assets")


@app.get("/")
def index():
    return FileResponse("frontend/dist/index.html")


@app.get("/favicon.ico")
def index():
    return FileResponse("frontend/dist/favicon.ico")


def get_camera(cam_name: Cameras) -> Camera:
    if cam_name == "hq":
        return system.hq_cam
    else:
        return system.aux_cam


@app.get("/cam/acquire/{cam_name}", response_class=ImageResponse)
def cam_acquire(cam_name: Cameras, scale: float = 0.2, encoding: Encodings = "jpeg", start_stop: bool = True):
    camera = get_camera(cam_name)

    if start_stop:
        camera.start()

    img = camera.acquire_array()

    if start_stop:
        camera.stop()

    # Encode the image if requested
    return ImageResponse(img, scale=scale, media_type=f"image/{encoding}")


@app.get("/cam/preview/start/{cam_name}")
def preview_start(cam_name: Cameras):
    camera = get_camera(cam_name)
    camera.start_preview()


@app.get("/cam/preview/stop/{cam_name}")
def preview_stop(cam_name: Cameras):
    camera = get_camera(cam_name)
    camera.stop_preview()


@app.get("/cam/start/{cam_name}")
def cam_start(cam_name: Cameras):
    get_camera(cam_name).start()


@app.get("/cam/stop/{cam_name}")
def cam_start(cam_name: Cameras):
    get_camera(cam_name).stop()


class Status(BaseModel):
    limit1: bool
    limit2: bool
    estop: bool
    running: bool
    led: bool
    position: int
    calibrated: bool
    hq_preview: bool
    aux_preview: bool


@app.get("/status", response_model=Status)
def state_position():
    position = system.stage.get_position()
    return {
        "limit1": system.stage.limit_1,
        "limit2": system.stage.limit_2,
        "estop": system.stage.estop,
        "running": system.stage.running,
        "led": system.stage.led,
        "position": position,
        "calibrated": system.stage.calibrated,
        "hq_preview": system.hq_cam.preview,
        "aux_preview": system.aux_cam.preview,
    }


StageStepSizes = Literal[
    "FULL",
    "HALF",
    "QUARTER",
    "EIGHTH"
]

StageStepSizesMap = {
    "FULL": StageStepSize.FULL,
    "HALF": StageStepSize.HALF,
    "QUARTER": StageStepSize.QUARTER,
    "EIGHTH": StageStepSize.EIGHTH
}


@app.post("/stage/relative")
def stage_relative(n: int, size: StageStepSizes, ignore_limits: bool = False):
    system.stage.relative(n, StageStepSizesMap[size], ignore_limits)
    system.stage.wait()


@app.post("/stage/absolute")
def stage_absolute(n: int, size: StageStepSizes = "EIGHTH", ignore_limits: bool = False):
    system.stage.absolute(n, StageStepSizesMap[size], ignore_limits)
    system.stage.wait()


@app.post("/stage/set_position")
def stage_absolute(position: int):
    system.stage.set_position(position)


@app.post("/stage/speed")
def stage_speed(hz: int):
    system.stage.speed(hz)


@app.post("/stage/led_pwm")
def stage_speed(pwm: float):
    system.stage.led_pwm(pwm)


@app.post("/stage/step_off")
def stage_speed(n: int, size: StageStepSizes = "EIGHTH"):
    system.stage.switch_step_off(StageStepSizesMap[size], n)


@app.get("/system/estop")
def estop(stop: bool):
    if stop:
        system.stage.emergency_stop()
    else:
        system.stage.emergency_clear()


@app.get("/future/{fid}")
async def get_future(fid: int):
    img = await future_manager.get(fid)

    # Free up resources (should free the image)
    future_manager.delete(fid)
    return img


@app.get("/sfuture/{fid}")
def get_sequenced_future(fid: int):
    res = sequenced_future_manager.get(fid)
    if res is None:
        raise HTTPException(status_code=204, detail="No more content")
    return res


@app.post("/system/single_card")
async def single_card(
        encoding: Encodings = "jpeg",
        initial_position: int = 2500,
        light_pwm: float = 0.2,
        scale: float = 0.2,
        delay: float = 0.2,
        speed: int = 1500,
        stage_offsets: typing.Annotated[typing.List[int], Query()] = (350, 350, 350, 350, 350, 350),
        step_size: StageStepSizes = "QUARTER",
        buffer: bool = False
):
    # Generate the futures for the frontend to request these images
    futures = []
    fids = []
    for _ in stage_offsets:
        fid, future = future_manager.create()
        futures.append(future)
        fids.append(fid)

    def execute():
        system.stage.led_pwm(light_pwm)
        if buffer:
            # First gather all the images
            images = []
            for image in system.single_card(
                    initial_position,
                    delay, speed, stage_offsets,
                    StageStepSizesMap[step_size]
            ):
                images.append(image)

            # Now reply to the futures
            for i, image in enumerate(images):
                futures[i].set_result(ImageResponse(image, scale=scale, media_type=f"image/{encoding}"))
        else:
            # Reply to the futures as they come
            # This encodes in-between each step
            for i, image in enumerate(system.single_card(
                    initial_position,
                    delay, speed, stage_offsets,
                    StageStepSizesMap[step_size]
            )):
                futures[i].set_result(ImageResponse(image, scale=scale, media_type=f"image/{encoding}"))
        system.stage.led_pwm(0)

    # Actually execute the request
    # Do this asynchronously
    thread = threading.Thread(target=execute)
    thread.start()

    # Get all the required futures
    return fids


@app.post("/system/align")
def system_align(
        light_pwm: float = 0.2,
        coarse_n: int = 300,
        coarse_size: StageStepSizes = "QUARTER",
        laplacian_threshold: float = 12.0,
        num_points_threshold: int = 100,
        standard_deviation_threshold: float = 100.0,
        vertical_rad_threshold: float = 0.5,
        step_delay: float = 0.2
):
    system.stage.led_pwm(light_pwm)
    for _ in system.align(coarse_n, StageStepSizesMap[coarse_size],
                          laplacian_threshold, num_points_threshold,
                          standard_deviation_threshold,
                          vertical_rad_threshold, step_delay,
                          debug=False):
        pass
    system.stage.led_pwm(0)


@app.post("/system/debug_align")
async def system_debug_align(
        light_pwm: float = 0.2,
        coarse_n: int = 300,
        coarse_size: StageStepSizes = "QUARTER",
        laplacian_threshold: float = 12.0,
        num_points_threshold: int = 100,
        standard_deviation_threshold: float = 100.0,
        vertical_rad_threshold: float = 0.5,
        step_delay: float = 0.2
):
    fid = sequenced_future_manager.create()

    def run_alignment():
        system.stage.led_pwm(light_pwm)
        for img in system.align(coarse_n, StageStepSizesMap[coarse_size],
                                laplacian_threshold, num_points_threshold,
                                standard_deviation_threshold,
                                vertical_rad_threshold, step_delay,
                                debug=True):
            sequenced_future_manager.put(fid, ImageResponse(img, scale=1))
        system.stage.led_pwm(0)
        sequenced_future_manager.finish(fid)

    threading.Thread(target=run_alignment, daemon=True).start()
    return fid


@app.post("/system/card_id")
def system_card_id(
        scale: float = 1,
        start_row: int = 1150,
        end_row: int = 1300,
        start_col: int = 600,
        end_col: int = 1250,
        position: int = 8200,
        light_level: float = 0,
        step_size: StageStepSizes = "QUARTER",
        return_img: bool = True
):
    system.approach_absolute(position, size=StageStepSizesMap[step_size])
    system.stage.led_pwm(light_level)

    with system.aux_cam:
        img = system.aux_cam.acquire_array()
        card_id, img = processing.card_id(img, scale, start_row, end_row, start_col, end_col)

    if return_img:
        return ImageResponse(img, scale=1)
    else:
        return card_id


class Mount(BaseModel):
    device: str
    mountpoint: str
    fs_type: str
    options: str
    dump_freq: int
    parallel_fsck: int

    def __init__(self, mtab_line: str):
        device, mountpoint, fs_type, options, dump_freq, parallel_fsck = mtab_line.split()
        super().__init__(
            device=device,
            mountpoint=mountpoint,
            fs_type=fs_type,
            options=options,
            dump_freq=int(dump_freq),
            parallel_fsck=int(parallel_fsck)
        )


@app.post("/linux/mounts")
def linux_usb(
        mount_point_filter: Optional[str] = None,
        fs_type_filter: Optional[str] = None
):
    if mount_point_filter is None and fs_type_filter is None:
        raise ValueError("mount_point and fs_type filters can not both be none")

    # Check for USBs
    out: typing.List[Mount] = []
    with open("/proc/mounts") as mounts:
        for line in mounts:
            filter_is_good = True
            mount = Mount(line)
            if mount_point_filter is not None:
                filter_is_good = filter_is_good and mount_point_filter in mount.mountpoint

            if fs_type_filter is not None:
                filter_is_good = filter_is_good and fs_type_filter in mount.fs_type

            if filter_is_good:
                out.append(mount)

    return out


@app.post("/linux/unmount")
def linux_unmount(mountpoint: str):
    out = os.system(f"umount {mountpoint}")
    assert out == 0, "Umount call failed"


class SingleCardParameters(BaseModel):
    encoding: Encodings = "jpeg"
    light_pwm: float = 0.2
    initial_position: int = 2500
    scale: float = 0.2
    delay: float = 0.2
    speed: int = 2000
    stage_offsets: typing.List[int] = (350, 350, 350, 350, 350)
    step_size: StageStepSizes = "QUARTER"


class CardIDParameters(BaseModel):
    scale: float = 1,
    start_row: int = 1150,
    end_row: int = 1300,
    start_col: int = 600,
    end_col: int = 1250,
    position: int = 8200,
    light_level: float = 0
    step_size: StageStepSizes = "QUARTER"


class RunParams(BaseModel):
    sensor: Optional[SingleCardParameters]
    card_id: Optional[CardIDParameters]
    path: str


def rename_card_id(path: str, subdir: str, to_id: str):
    mount_point_path = Path(path)
    assert mount_point_path.exists() and mount_point_path.is_dir()

    stor = Storage.open(mount_point_path)
    for card in stor.cards:
        if subdir == card.subdir_path:
            assert (mount_point_path / card.subdir_path).exists() and (mount_point_path / card.subdir_path).is_dir()

            new_subdir_items = card.subdir_path.split("-")
            new_subdir_items[-1] = to_id
            new_subdir = "-".join(new_subdir_items)

            with (mount_point_path / card.subdir_path / "card_id.gt.txt").open("w+") as f:
                f.write(to_id)

            os.rename(
                mount_point_path / card.subdir_path,
                mount_point_path / new_subdir
            )

            card.subdir_path = new_subdir
            card.card_id = to_id
            stor.save()
            return {
                "card_id": to_id,
                "subdir": new_subdir
            }

    raise ValueError("No card acquisition found")


@app.post("/system/run")
async def run(request: RunParams):
    mount_point_path = Path(request.path)
    assert mount_point_path.exists() and mount_point_path.is_dir()

    if request.sensor is None:
        request.sensor = SingleCardParameters()
    if request.card_id is None:
        request.card_id = CardIDParameters()

    # Generate the futures for the frontend to request these images
    futures = []
    fids = []
    for _ in range(len(request.sensor.stage_offsets) + 2):
        fid, future = future_manager.create()
        futures.append(future)
        fids.append(fid)

    encoding_queue = Queue[Tuple[int, np.ndarray]]()

    acquisition_time = datetime.datetime.now()
    subdir = acquisition_time.strftime(f"%Y-%m-%d-%H-%M-%S-tmp")
    output_path = mount_point_path / subdir
    output_path.mkdir(parents=True)

    def encode_worker():
        while True:
            i, img = encoding_queue.get()

            if request.sensor.encoding == "jpeg":
                cv2.imwrite(str(output_path / f"{i}.jpg"), img)
            elif request.sensor.encoding == "png":
                cv2.imwrite(str(output_path / f"{i}.png"), img)
            elif request.sensor.encoding == "tiff":
                cv2.imwrite(str(output_path / f"{i}.tiff"), img)

            encoding_queue.task_done()

    # Boot up the encoder worker
    threading.Thread(target=encode_worker, daemon=True).start()

    def execute():
        # Run all the sensor captures
        # Start up both cameras to reduce startup overhead
        try:
            system.hq_cam.start()

            system.stage.led_pwm(request.sensor.light_pwm)

            system.stage.speed(request.sensor.speed)
            system.approach_absolute(request.sensor.initial_position, size=StageStepSizesMap[request.sensor.step_size])
            for i, pos in enumerate(request.sensor.stage_offsets):
                if request.sensor.delay > 0:
                    time.sleep(request.sensor.delay)

                img = system.hq_cam.acquire_array()

                # Queue the image to be encoded and written to disk
                encoding_queue.put((i, img))

                log.info("Acquired %d/%d", i + 1, len(request.sensor.stage_offsets))

                # No need to buffer since we are encoding with preview size
                futures[i].set_result(ImageResponse(img, scale=request.sensor.scale))

                # Move to the next image
                system.stage.relative(
                    pos,
                    StageStepSizesMap[request.sensor.step_size],
                )
                system.stage.wait(granularity=0.05)

            # Move to where the out camera can take an image
            # (Move quickly)
            log.info("Detecting card ID")
            system.stage.led_pwm(request.card_id.light_level)
            system.approach_absolute(request.card_id.position, size=StageStepSizesMap[request.card_id.step_size])

            # Save images and files to disk
            # Do this while we wait for the card to move to Aux position
            card = Card(
                card_id="tmp",
                stage_offsets=request.sensor.stage_offsets,
                acquisition_time=acquisition_time,
                subdir_path=subdir,
                image_format=request.sensor.encoding
            )

            # Grab an aux image and process it
            with system.aux_cam:
                card_id_img = system.aux_cam.acquire_array()
            card_id, card_id_img_proc = processing.card_id(
                card_id_img,
                request.card_id.scale,
                request.card_id.start_row,
                request.card_id.end_row,
                request.card_id.start_col,
                request.card_id.end_col
            )

            # This encoding should be pretty fast since the image is tiny
            cv2.imwrite(str(output_path / f"card_id.png"), card_id_img_proc)
            with (output_path / f"card_id.gt.txt").open("w+") as f:
                f.write(card_id)

            # Write to the listings file
            Storage.open(mount_point_path).add_card(card)

            # Resolve the final future
            futures[-2].set_result(ImageResponse(card_id_img_proc, scale=1))

            encoding_queue.join()

            futures[-1].set_result(rename_card_id(request.path, subdir, card_id))

        finally:
            system.stage.led_pwm(0)
            system.hq_cam.stop()

    # Actually execute the request
    # Do this asynchronously
    thread = threading.Thread(target=execute)
    thread.start()

    # Get all the required futures
    return fids


@app.post("/system/rename")
def rename(
        path: str,
        subdir: str,
        to_id: str
):
    return rename_card_id(path, subdir, to_id)


@app.get("/system/cards")
def get_cards(path: str):
    p_path = Path(path)
    assert p_path.exists() and p_path.is_dir()

    stor = Storage.open(p_path)
    return stor.cards


@app.get("/system/card/view")
def get_card(path: str, subdir: str, img: int, encoding: Encodings):
    read_path = Path(path) / subdir
    assert read_path.is_dir()

    if encoding == "jpeg":
        img = cv2.imread(str(read_path / f"{img}.jpg"))
    elif encoding == "png":
        img = cv2.imread(str(read_path / f"{img}.png"))
    elif encoding == "tiff":
        img = cv2.imread(str(read_path / f"{img}.tiff"))
    else:
        assert False, f"Invalid Encoding {encoding}"

    return ImageResponse(img)


@app.get("/system/card/delete")
def delete_card(path: str, subdir: str):
    # Search for this card in the listings
    stor = Storage.open(Path(path))
    del_idx = -1
    for i, card in enumerate(stor.cards):
        if card.subdir_path == subdir:
            del_idx = i
            break

    assert del_idx != -1, f"Subdir {subdir} not found in {path}"
    del stor.cards[del_idx]
    stor.save()

    del_path = Path(path) / subdir
    assert del_path.is_dir()
    shutil.rmtree(del_path)


@app.get("/system/card/download")
def card_download(path: str, subdir: str):
    fd, zip_path = tempfile.mkstemp(".zip")

    def cleanup():
        os.remove(zip_path)

    log.info("Zipping %s into %s", subdir, zip_path)
    cleanup()
    out = os.system(f"zip -rj {zip_path} {path}/{subdir}/")
    assert out == 0, "Zip call failed"

    return FileResponse(zip_path, background=BackgroundTask(cleanup))

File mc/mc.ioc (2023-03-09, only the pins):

Mcu.UserName=STM32L476RGTx
PA10.GPIO_Label=MS3
PA10.Signal=GPIO_Output
PA11.GPIO_Label=DIR
PA11.Signal=GPIO_Output
PA8.GPIO_Label=MS1
PA8.Signal=GPIO_Output
PA9.GPIO_Label=MS2
PA9.Signal=GPIO_Output
PB1.GPIO_Label=LIGHT_S
PB1.Signal=ADCx_IN16
PB12.GPIO_Label=SWITCH2
PB12.Signal=GPXTI12
PB14.GPIO_Label=SWITCH1
PB14.Signal=GPXTI14
PB15.GPIO_Label=ENABLE
PB15.Signal=GPXTI15
PB6.Signal=USART1_TX
PB7.Signal=USART1_RX
PB8.GPIO_Label=LIGHT
PB8.Signal=S_TIM4_CH3
PC12.GPIO_Label=LED
PC12.Signal=GPIO_Output
PC4.Signal=USART3_TX
PC5.Signal=USART3_RX
PC8.GPIO_Label=STEP
PC8.Signal=S_TIM3_CH3

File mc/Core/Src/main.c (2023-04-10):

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
/* Includes ------------------------------------------------------------------*/
#include "main.h"

/* USER CODE BEGIN Includes */
#include <motor.h>
#include <packet.h>
#include <switch.h>
#include <led.h>
/* USER CODE END Includes */

ADC_HandleTypeDef hadc1;
DMA_HandleTypeDef hdma_adc1;

TIM_HandleTypeDef htim3;
TIM_HandleTypeDef htim4;
TIM_HandleTypeDef htim5;
TIM_HandleTypeDef htim7;

UART_HandleTypeDef huart1;
UART_HandleTypeDef huart3;

void SystemClock_Config(void);
static void MX_GPIO_Init(void);
static void MX_DMA_Init(void);
static void MX_TIM3_Init(void);
static void MX_USART3_UART_Init(void);
static void MX_USART1_UART_Init(void);
static void MX_ADC1_Init(void);
static void MX_TIM4_Init(void);
static void MX_TIM5_Init(void);
static void MX_TIM7_Init(void);
/* USER CODE BEGIN 0 */

static int triggered = 0;

void HAL_GPIO_EXTI_Callback(uint16_t GPIO_Pin)
{
    if(GPIO_Pin == SWITCH1_Pin ||
       GPIO_Pin == SWITCH2_Pin ||
       GPIO_Pin == ENABLE_Pin)
    {
        switch_event(GPIO_Pin);
    }
}

/* USER CODE END 0 */

/**
  * @brief  The application entry point.
  * @retval int
  */
int main(void)
{
  /* MCU Configuration--------------------------------------------------------*/

  /* Reset of all peripherals, Initializes the Flash interface and the Systick. */
  HAL_Init();

  /* Configure the system clock */
  SystemClock_Config();

  /* Initialize all configured peripherals */
  MX_GPIO_Init();
  MX_DMA_Init();
  MX_TIM3_Init();
  MX_USART3_UART_Init();
  MX_USART1_UART_Init();
  MX_ADC1_Init();
  MX_TIM4_Init();
  MX_TIM5_Init();
  MX_TIM7_Init();
  /* USER CODE BEGIN 2 */

    switch_init(&htim7);
    led_init(&htim4, LIGHT_PWM_CHANNEL, &htim5);
    led_sensor_init(&hadc1);

    motor_init(&htim3, MOTOR_PWM_CHANNEL);
    packet_init(&huart1);

  /* USER CODE END 2 */

  /* Infinite loop */
  /* USER CODE BEGIN WHILE */
  while (1)
  {
      packet_task(&huart1);

    /* USER CODE END WHILE */

    /* USER CODE BEGIN 3 */
  }
  /* USER CODE END 3 */
}

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


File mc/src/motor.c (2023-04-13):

//
// Created by tumbar on 1/18/23.
//

#include "motor.h"
#include "log.h"

#include "main.h"
#include "switch.h"

static TIM_HandleTypeDef* step_timer = NULL;
static I32 step_channel = -1;

static I32 motor_position = 0;

static motor_step_t limit_step_off_size = MOTOR_STEP_EIGHTH;
static U32 limit_step_off_count = 300;
static Bool motor_has_failure_flag = FALSE;

static struct
{
    Bool direction_reversed;
    Bool is_running;
    motor_step_t step;
    I32 step_scalar;
    U16 i;
    U16 n;
    Bool direction;
    MotorReply reply_cb;
} motor_request = {
        .direction_reversed = FALSE,
        .is_running = FALSE,
        .step = MOTOR_STEP_FULL,
        .n = 0,
        .reply_cb = NULL,
};

I32 motor_get_step_size(motor_step_t step, Bool reversed)
{
    I32 scalar = reversed ? -1 : 1;

    switch(step)
    {
        case MOTOR_STEP_FULL: return scalar * 8;
        case MOTOR_STEP_HALF: return scalar * 4;
        case MOTOR_STEP_QUARTER: return scalar * 2;
        case MOTOR_STEP_EIGHTH:
        case MOTOR_STEP_SIXTEENTH:
            // 1/16 step on this controller will not
            // change the speed compared to 1/8
            return scalar * 1;
    }
}

Status motor_speed(U32 hz)
{
    if (motor_is_running())
    {
        return STATUS_FAILURE;
    }

    U16 arr = (SystemCoreClock / 80) / hz;
    U16 cmp = (arr / 2) - 1;

    __HAL_TIM_SET_COUNTER(step_timer, 0);
    __HAL_TIM_SET_AUTORELOAD(step_timer, arr - 1);
    __HAL_TIM_SET_COMPARE(step_timer, step_channel, cmp);

    return STATUS_SUCCESS;
}

void motor_init(void* step_timer_,
                I32 step_channel_)
{
    step_timer = step_timer_;
    step_channel = step_channel_;
}

void motor_tick(void)
{
    // Increment the position
    motor_position += motor_request.step_scalar;
    motor_request.i++;

    if (motor_request.i >= motor_request.n)
    {
        motor_stop(FALSE);
    }
}

void motor_stop(Bool motion_failure)
{
    HAL_TIM_PWM_Stop(step_timer, step_channel);

    MotorReply reply_cb = motor_request.reply_cb;

    motor_request.step = 0;
    motor_request.step_scalar = 0;
    motor_request.i = 0;
    motor_request.n = 0;
    motor_request.is_running = FALSE;
    motor_request.direction_reversed = FALSE;
    motor_request.reply_cb = NULL;

    motor_has_failure_flag = motion_failure;

    if (reply_cb)
    {
        reply_cb();
    }
}

Status motor_is_ready(motor_step_t step)
{
    switch(step)
    {
        case MOTOR_STEP_FULL:
        case MOTOR_STEP_HALF:
        case MOTOR_STEP_QUARTER:
        case MOTOR_STEP_EIGHTH:
        case MOTOR_STEP_SIXTEENTH:
            break;
        default:
            log_printf("Invalid step size %d", step);
            return STATUS_FAILURE;
    }

    if (motor_request.is_running)
    {
        log_printf("Motor is busy with another request");
        return STATUS_FAILURE;
    }

    return STATUS_SUCCESS;
}

Bool motor_is_running()
{
    return motor_request.is_running;
}

Bool motor_has_failure(void)
{
    return motor_has_failure_flag;
}

void motor_set_ms(motor_step_t step)
{
    HAL_GPIO_WritePin(MS1_GPIO_Port, MS1_Pin, (step & MOTOR_PIN_MS1) ? GPIO_PIN_SET : GPIO_PIN_RESET);
    HAL_GPIO_WritePin(MS2_GPIO_Port, MS2_Pin, (step & MOTOR_PIN_MS2) ? GPIO_PIN_SET : GPIO_PIN_RESET);
    HAL_GPIO_WritePin(MS3_GPIO_Port, MS3_Pin, (step & MOTOR_PIN_MS3) ? GPIO_PIN_SET : GPIO_PIN_RESET);
}

static Bool motor_is_stepping_off = FALSE;

static void motor_limit_step_off_done(void)
{
    motor_is_stepping_off = FALSE;
}

void motor_limit_step_off(void)
{
    // Don't step off the limit switch if we are not
    // currently running a motion.
    // Also ignore limit switch events during step off
    if (!motor_request.is_running || motor_is_stepping_off)
    {
        return;
    }

    // Run the motor the other direction
    Bool is_reversed = !motor_request.direction_reversed;

    motor_stop(TRUE);
    motor_is_stepping_off = TRUE;

    // Step off the limit switch by running the motor backwards
    motor_step(limit_step_off_size,
               limit_step_off_count,
               is_reversed,
               motor_limit_step_off_done,
               TRUE);
}

void motor_set_limit_step_off(motor_step_t step, U32 nstep)
{
    limit_step_off_size = step;
    limit_step_off_count = nstep;
}

Status motor_step(
        motor_step_t step, U16 n,
        Bool direction_reversed,
        MotorReply reply_cb,
        Bool ignore_limits)
{
    if (motor_is_ready(step) != STATUS_SUCCESS)
    {
        return STATUS_FAILURE;
    }

    // Check if we are against the limit switches
    if (!ignore_limits)
    {
        if (switch_limit_1_get() ||
            switch_limit_2_get() ||
            switch_e_stop_get())
        {
            return STATUS_FAILURE;
        }

        // A non limit ignore will clear the failure flag
        motor_has_failure_flag = FALSE;
    }
    else if (switch_e_stop_get())
    {
        return STATUS_FAILURE;
    }

    if (n == 0)
    {
        return STATUS_SUCCESS;
    }

    motor_request.step = step;
    motor_request.step_scalar = motor_get_step_size(step, direction_reversed);
    motor_request.i = 0;
    motor_request.n = n;
    motor_request.is_running = TRUE;
    motor_request.direction_reversed = direction_reversed;
    motor_request.reply_cb = reply_cb;

    // Set up the step size logic levels
    motor_set_ms(motor_request.step);

    // Go forwards or backwards
    HAL_GPIO_WritePin(DIR_GPIO_Port, DIR_Pin,
                      motor_request.direction_reversed ? GPIO_PIN_SET : GPIO_PIN_RESET);

    // The PWM timer. @500Hz, timer each timer tick is a single motor step
    HAL_TIM_PWM_Start_IT(step_timer, step_channel);

    return STATUS_SUCCESS;
}

I32 motor_get_position(void)
{
    return motor_position;
}

void motor_set_position(const I32 position)
{
    motor_position = position;
}

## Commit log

2022-09-25 Added more sequenceres, connected camera to videoStreamer
2022-11-04 Still and Video camera streams
2022-11-14 Started python switch
2023-01-19 Started motor driver
2023-01-19 Finished motor_step commanding
2023-01-24 Timer based motor driver
2023-02-06 Count motor steps
2023-02-08 Switched to stm32l476rg chip
2023-02-15 Design PCB, switch to L4 chip
    [WerfenMc-B_Cu.gbr, WerfenMc-B_Mask.gbr, WerfenMc-B_Paste.gbr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]
2023-02-15 Added a via to motor driver ground, exported better step file
    [WerfenMc_power_edit.kicad_pcb]
2023-03-02 Finished packet_task, wrote led voltage controller, write pi side driver
    [WerfenMc_BOM.csv, WerfenMc_power_edit.csv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]
2023-03-02 Turn off ms line LEDs after motor request is done
    [WerfenMc_power_edit.kicad_pcb]
2023-03-02 Implemented absolute commanding, turn off LEDs when motor is finished
2023-03-03 Added docstring to all functions in stage
2023-03-06 Working stage
2023-03-06 250 Hz step
2023-03-08 Reverse engineer the actual layout with the new schottkey (whoops)
    [WerfenMc_power_edit.kicad_pcb, WerfenMc_power_edit.kicad_sch]
2023-03-08 Implement dynamic motor trigger
2023-03-09 Implement debounce on limit switches, long commands, stage wait for finish, motor stop
2023-03-09 Wrote cam driver
2023-03-09 Granular waits between sensor moves
2023-03-20 Python 3.9 updates
    [WerfenMc_estop_fix.kicad_sch]
2023-04-05 Started gui and fastapi
    [WerfenMc_estop_fix.kicad_sch]
2023-04-05 Init main.py with correct hardware
    [main.py]
2023-04-05 Fix dummy serial driver
    [main.py, stage.py]
2023-04-05 Swap ui for reactjs
    [main.py]
2023-04-05 Fix checksum issue in firmware
    [packet.c]
2023-04-06 Add limit switch step off
2023-04-10 Add failure flag to indicate limit switch hit
    [led.c, main.c, main.h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]
2023-04-12 Better alignment error finding, added edge num points threshold
    [main.py, processing.py, system.py]
2023-04-13 Added calibrated flag to PCB
2023-04-13 Add calibrated to frontend
2023-04-13 Fix fault on limit
    [stage.py]
2023-04-13 Add unmount button
2023-04-13 Ask for alignment if not calibrated
2023-04-15 Perform encode during stage motion
2023-04-17 Initial pose approach use correct step size
    [main.py]
2023-04-21 Added focus buttons
2023-04-22 Added stage controls on focus
2023-04-24 Correct ar for imx477
    [cam.py]
2023-04-24 Add notification for pcb failures

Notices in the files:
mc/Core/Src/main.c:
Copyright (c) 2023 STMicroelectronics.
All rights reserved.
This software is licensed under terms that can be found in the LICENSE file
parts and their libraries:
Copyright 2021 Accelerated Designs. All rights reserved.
